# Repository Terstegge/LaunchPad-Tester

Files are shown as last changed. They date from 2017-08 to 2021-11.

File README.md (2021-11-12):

# LaunchPad-Tester
This is a small TI-LaunchPad compatible boosterpack board,
which can be used for testing all GPIO pins on a TI LaunchPad.

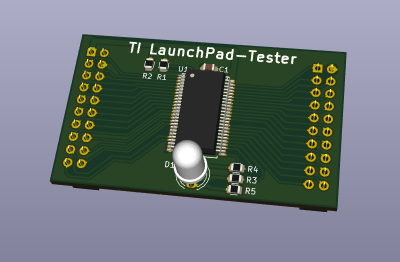
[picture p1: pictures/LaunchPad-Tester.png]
LaunchPad-Tester as 3D model


_Background:_ When using TI LaunchPads for educational purposes,
some of the IO-pins might be destroyed by students. So I needed
a simple way to test all IO pins of such boards before using
the boards during the next semester.

I had some spare [CY8C9540A](http://www.cypress.com/file/37971/download)
chips from Cypress and some 5mm 3-color LEDS, which are now used on
this board. The CY8C9540A is a GPIO expander with 40 IO pins and a
(slow) I2C interface. It also supports a programmable PWM signal on
all pins. Two of the LaunchPad IO pins are used for the I2C interface
to operate the CY8C9540A. When the CY8C9540A is not detected by the
LaunchPad, we at least know that these two pins are not working :).

When the CY8C9540A is detected by software, we can test every single
LaunchPad pin in input- and output-mode by programming the connected
CY8C9540A-pin.

The 3-color LED can be used to show the results of the tests.

This project contains the hardware design files, which were developed
using [KiCad EDA](http://kicad.org/). The related software will be
published in a separate project.

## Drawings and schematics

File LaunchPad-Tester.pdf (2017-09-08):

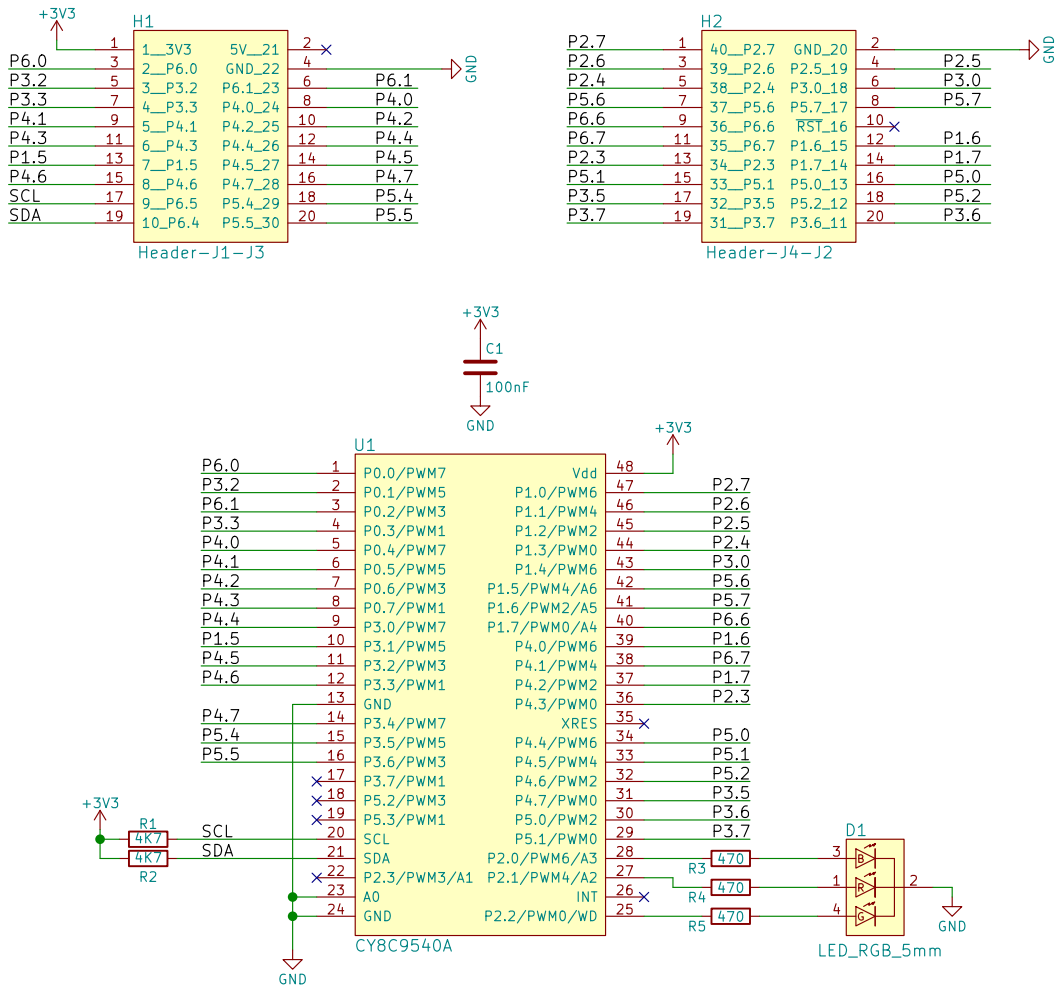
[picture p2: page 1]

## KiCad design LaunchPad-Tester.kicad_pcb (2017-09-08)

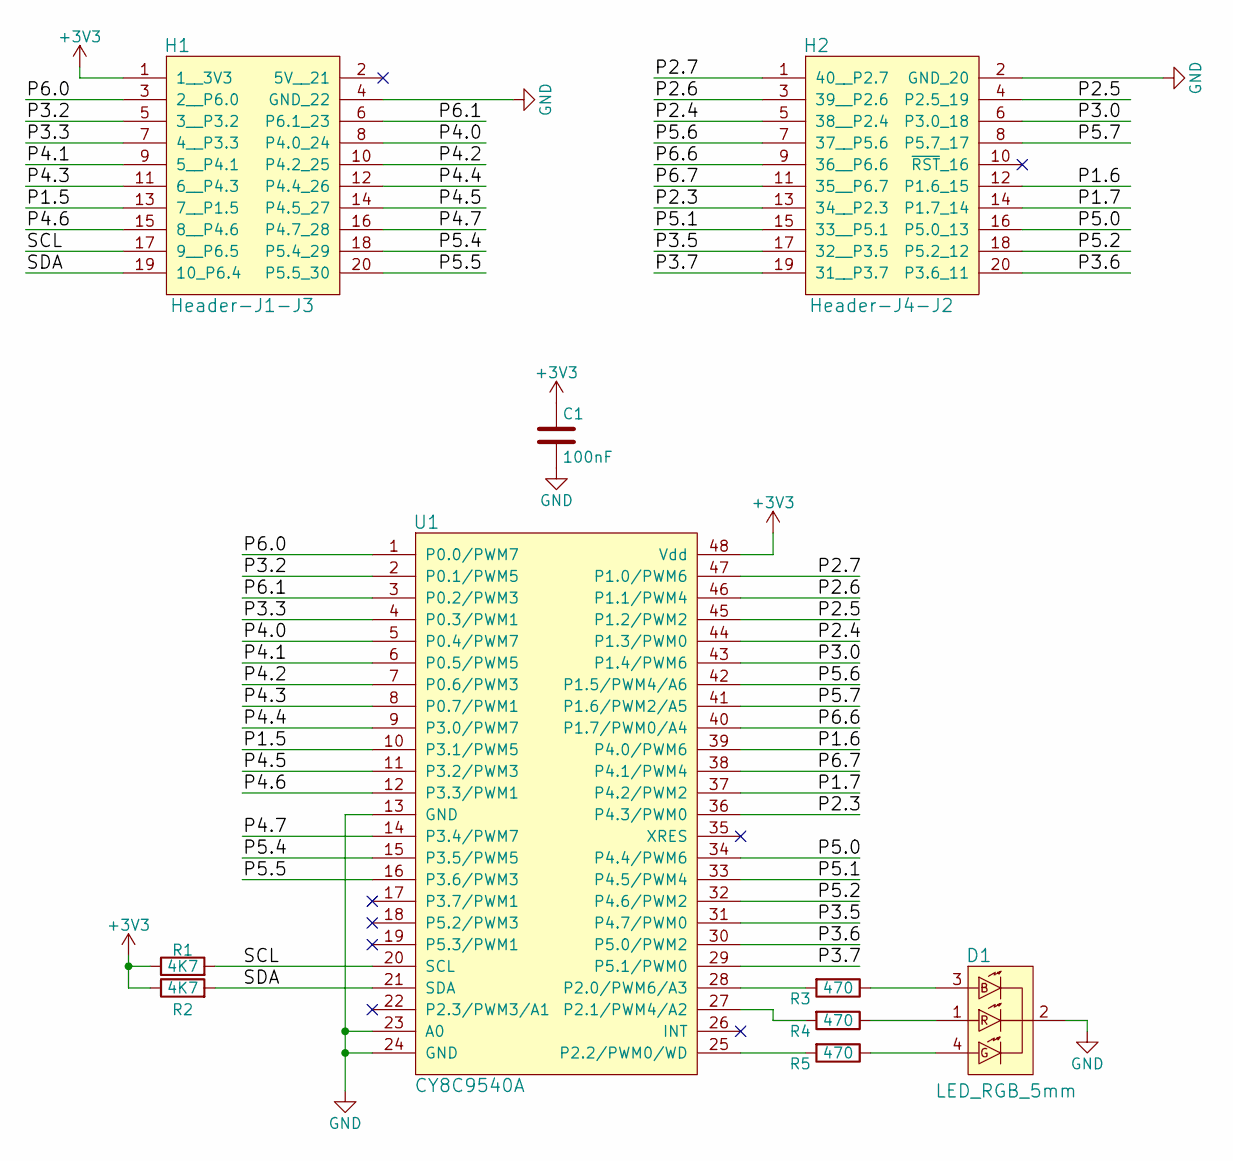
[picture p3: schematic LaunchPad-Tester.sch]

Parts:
C1: 100nF; C_0805
D1: LED_RGB_5mm; LED_D5.0mm-4
H1: Header-J1-J3; Socket_Strip_Straight_2x10_Pitch2.54mm
H2: Header-J4-J2; Socket_Strip_Straight_2x10_Pitch2.54mm
R1, R2: 4K7; R_0805
R3, R4, R5: 470; R_0805
U1: CY8C9540A; SSOP-48_7.5x15.9mm_Pitch0.635mm

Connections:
+3V3: C1.1, H1.1 (1__3V3), R1.1, R2.1, U1.48 (Vdd)
/P1.5: H1.13 (7__P1.5), U1.10 (P3.1/PWM5)
/P1.6: H2.12 (P1.6_15), U1.39 (P4.0/PWM6)
/P1.7: H2.14 (P1.7_14), U1.37 (P4.2/PWM2)
/P2.3: H2.13 (34__P2.3), U1.36 (P4.3/PWM0)
/P2.4: H2.5 (38__P2.4), U1.44 (P1.3/PWM0)
/P2.5: H2.4 (P2.5_19), U1.45 (P1.2/PWM2)
/P2.6: H2.3 (39__P2.6), U1.46 (P1.1/PWM4)
/P2.7: H2.1 (40__P2.7), U1.47 (P1.0/PWM6)
/P3.0: H2.6 (P3.0_18), U1.43 (P1.4/PWM6)
/P3.2: H1.5 (3__P3.2), U1.2 (P0.1/PWM5)
/P3.3: H1.7 (4__P3.3), U1.4 (P0.3/PWM1)
/P3.5: H2.17 (32__P3.5), U1.31 (P4.7/PWM0)
/P3.6: H2.20 (P3.6_11), U1.30 (P5.0/PWM2)
/P3.7: H2.19 (31__P3.7), U1.29 (P5.1/PWM0)
/P4.0: H1.8 (P4.0_24), U1.5 (P0.4/PWM7)
/P4.1: H1.9 (5__P4.1), U1.6 (P0.5/PWM5)
/P4.2: H1.10 (P4.2_25), U1.7 (P0.6/PWM3)
/P4.3: H1.11 (6__P4.3), U1.8 (P0.7/PWM1)
/P4.4: H1.12 (P4.4_26), U1.9 (P3.0/PWM7)
/P4.5: H1.14 (P4.5_27), U1.11 (P3.2/PWM3)
/P4.6: H1.15 (8__P4.6), U1.12 (P3.3/PWM1)
/P4.7: H1.16 (P4.7_28), U1.14 (P3.4/PWM7)
/P5.0: H2.16 (P5.0_13), U1.34 (P4.4/PWM6)
/P5.1: H2.15 (33__P5.1), U1.33 (P4.5/PWM4)
/P5.2: H2.18 (P5.2_12), U1.32 (P4.6/PWM2)
/P5.4: H1.18 (P5.4_29), U1.15 (P3.5/PWM5)
/P5.5: H1.20 (P5.5_30), U1.16 (P3.6/PWM3)
/P5.6: H2.7 (37__P5.6), U1.42 (P1.5/PWM4/A6)
/P5.7: H2.8 (P5.7_17), U1.41 (P1.6/PWM2/A5)
/P6.0: H1.3 (2__P6.0), U1.1 (P0.0/PWM7)
/P6.1: H1.6 (P6.1_23), U1.3 (P0.2/PWM3)
/P6.6: H2.9 (36__P6.6), U1.40 (P1.7/PWM0/A4)
/P6.7: H2.11 (35__P6.7), U1.38 (P4.1/PWM4)
/SCL: H1.17 (9__P6.5), R1.2, U1.20 (SCL)
/SDA: H1.19 (10_P6.4), R2.2, U1.21 (SDA)
GND: C1.2, D1.2, H1.4 (GND_22), H2.2 (GND_20), U1.13 (GND), U1.23 (A0), U1.24 (GND)
unnamed: D1.1, R4.1
unnamed: D1.3, R3.1
unnamed: D1.4, R5.1
unnamed: R3.2, U1.28 (P2.0/PWM6/A3)
unnamed: R4.2, U1.27 (P2.1/PWM4/A2)
unnamed: R5.2, U1.25 (P2.2/PWM0/WD)

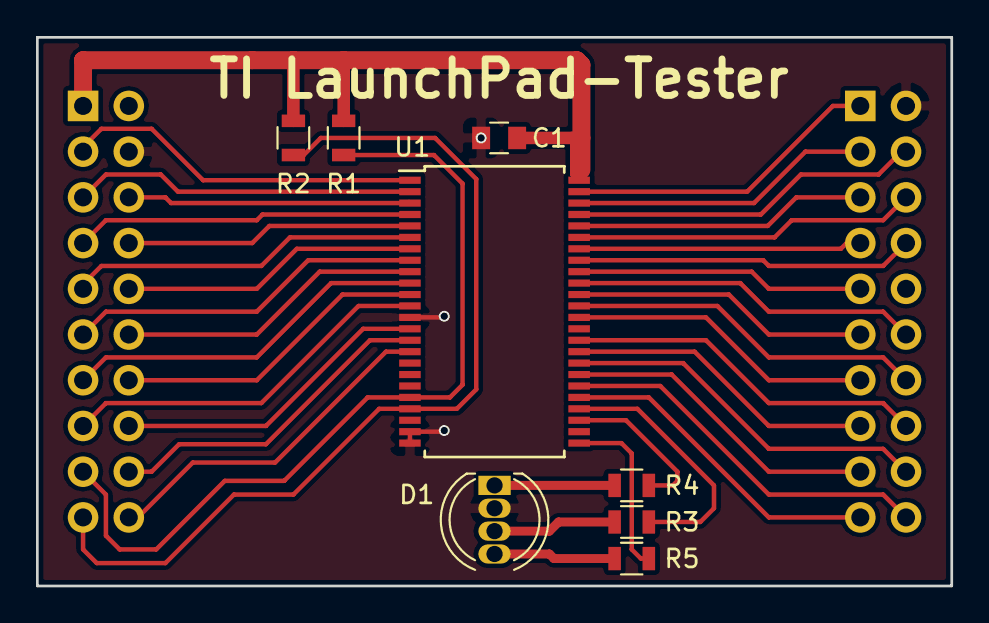
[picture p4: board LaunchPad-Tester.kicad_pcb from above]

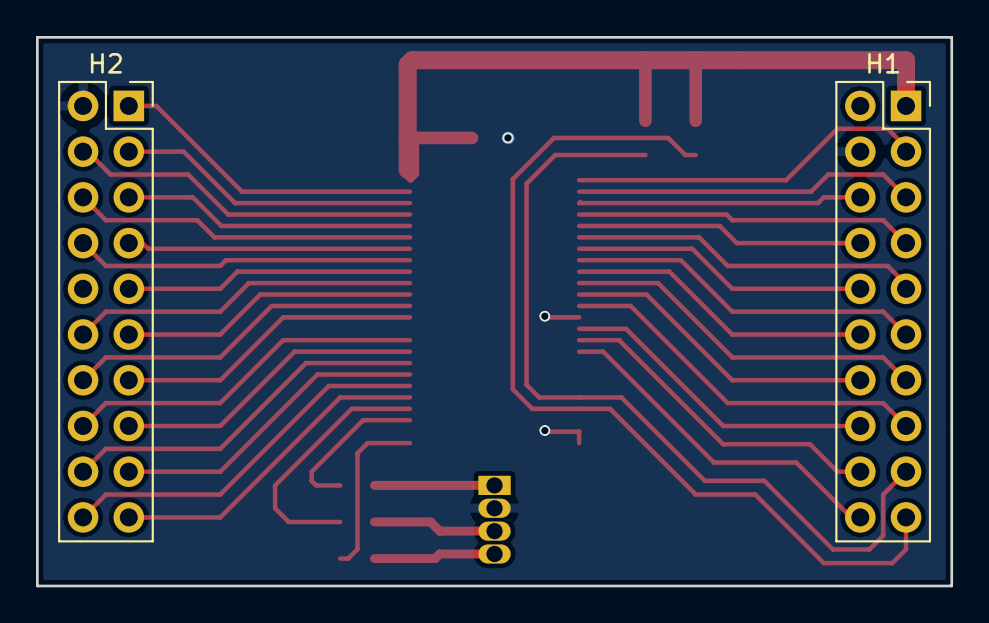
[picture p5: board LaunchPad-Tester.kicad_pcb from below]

Board: 2 copper layers, 50.8 x 30.5 mm, 10 parts (2 on the bottom side), 43 nets.

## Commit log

2017-08-24 First version of Launchpad Tester. Maybe also the last version ;)
    [LaunchpadTester-B.Cu.gbr, LaunchpadTester-B.Mask.gbr, LaunchpadTester-B.Paste.gbr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]
2017-08-24 Added picture of board.
2017-08-24 Added schematics as PDF file.
2017-09-08 Renamed project to LaunchPad-Tester and coorected some typos.
    [LaunchPad-Tester-B.Cu.gbr, LaunchPad-Tester-B.Mask.gbr, LaunchPad-Tester-B.Paste.gbr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]
2021-11-12 Updated link to KiCad.
